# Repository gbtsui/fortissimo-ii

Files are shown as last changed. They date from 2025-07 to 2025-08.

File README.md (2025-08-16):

# fortissimo ii

Hello world!

This is my 2nd attempt at building a keyboard.

I really enjoyed hackpad v2 (even though mine ended up broken...) and I wanted an extra little challenge to build something bigger and get better at soldering. So I designed this ortholinear split keyboard that's ideally meant to be perfect for me; ergonomic design, looks cool, a lot of functionality, and on-the-fly custom language switching (eventually - firmware hasn't caught up to that yet!). Since I'm planning on phasing out my laptop when the school year starts to avoid distractions a bit better, I'm going to hopefully replace it with an iPad so I can take notes more effectively. But because I don't have enough money for an iPad keyboard (I'm not shelling out another $160 after buying a $400 device plus a $100 pencil), and I wanted to challenge myself to design something that might be able to replace it, I designed this instead.

Maybe it's not the prettiest case (blame my awful CAD skills, also it's actually asymmetrical in size) and doesn't have the most beautiful design (I'm no electrical engineer), but hopefully it'll work. 

Also, yes, this keyboard is piano themed. I like pianos. I am not good at playing piano. But I thought it was a cool concept.

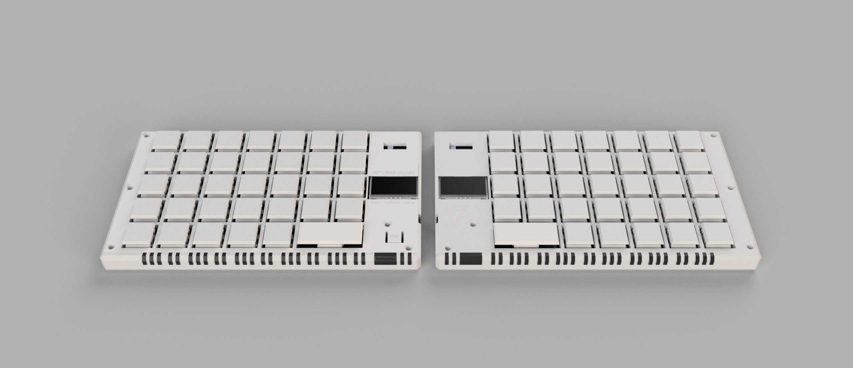
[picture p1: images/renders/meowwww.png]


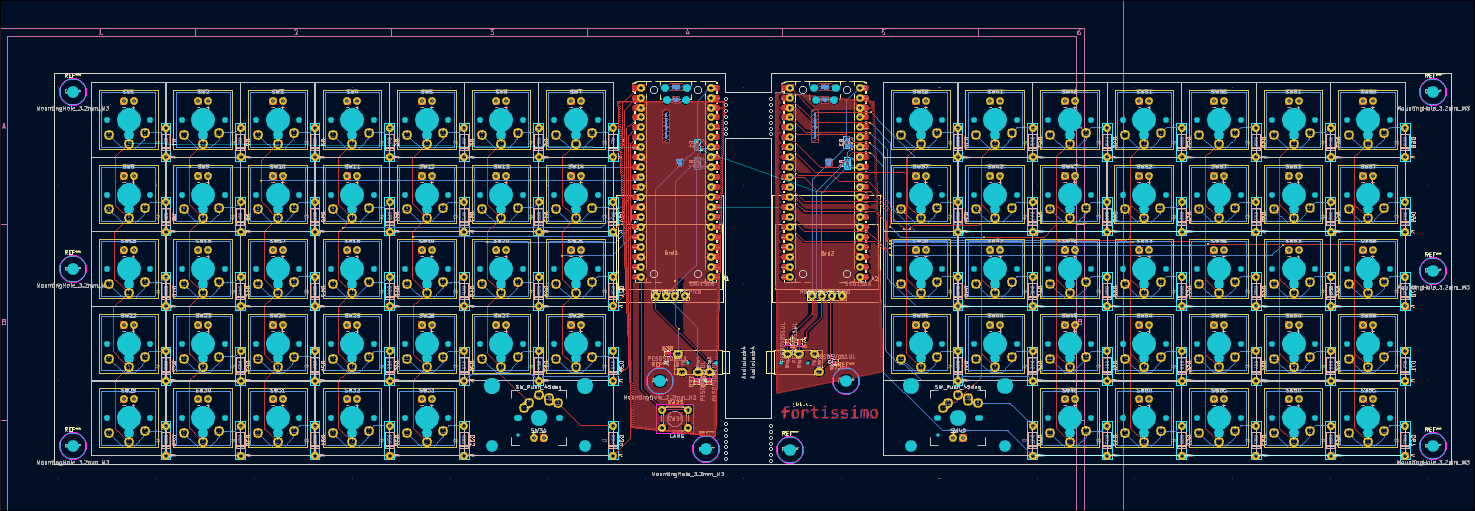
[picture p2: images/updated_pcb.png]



## Bill of Materials

| Item | Cost (each) | Quantity | Subtotal | Shipping |
|---|---|---|---|---|
|[kailh choc v1 brown](https://chosfox.com/collections/kailh-low-profile-switch-pg1350/products/kailh-chocs?variant=42514647646402) | $0.48 (10 pack) | 70 | $33.60 | $8.45 |
|[trrs jack](https://www.aliexpress.com/item/32368285821.html) | $0.069 (20 pack) | 2 | $1.38 | $4.35 |
|[128x64 SSD1306 OLED](https://www.aliexpress.com/item/1005006700828250.html) | $1.15 | 2 | $2.30 | Free Shipping |
| digikey |---|---|---|$8.00|
|[1N4148FS-ND matrix diodes](https://www.digikey.ca/en/products/detail/onsemi/1N4148/458603) | $0.0486 (100 pack) | 70 | $4.86 | - |
|[PESD5V0S1UL ESD protection diode](https://www.digikey.ca/en/products/detail/nexperia-usa-inc/PESD5V0S1BA-QF/18108466) | $0.311 (10 pack) | 6 | $3.11 | - |
|[6mm tactile switch](https://www.digikey.ca/en/products/detail/same-sky-formerly-cui-devices-/TS02-66-50-BK-100-LCR-D/15634294) | $0.15 | 1 | $0.15 | - |
|[raspberry pi pico](https://www.digikey.ca/en/products/detail/raspberry-pi/SC0915/13684020) | $5.75 | 1 | $5.75 | - |
|[4.7k pull up resistor](https://www.digikey.ca/en/products/detail/yageo/RC0603FR-074K7L/727212) | $0.014 (10 pack) | 4 | $0.14 | - |
|[header pin](https://www.digikey.ca/en/products/detail/w-rth-elektronik/61301611121/4846854) | $1.25 | 1 | $1.25 | - | 
|[M3 10mm heatset insert](https://www.digikey.ca/en/products/detail/adafruit-industries-llc/4255/10244656) | $0.1826 (50 pack) | 10 | $9.13 | - |
|[M3 10mm screw](https://www.digikey.ca/en/products/detail/apm-hexseal/RM3X10MM-2701/3712296) | $0.753 (10 pack) | 10 | $7.53 | - |
|PCB| $6.69 (5 pack, including shipping) |  1 | $17.60 | $12.67 + $3.17 | 

Total: $123.44

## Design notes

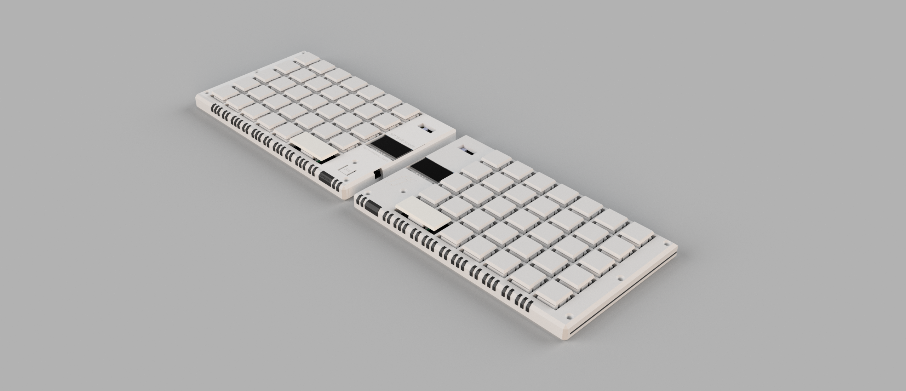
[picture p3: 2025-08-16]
images/renders/awww tism.png

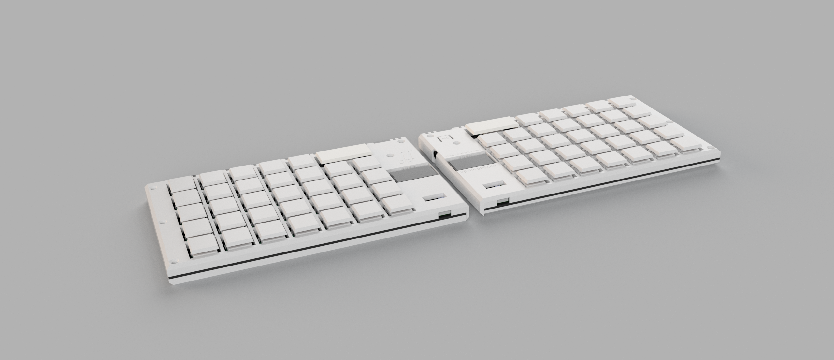
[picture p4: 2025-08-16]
images/renders/my seventheeth lemon, this one is called utah.png

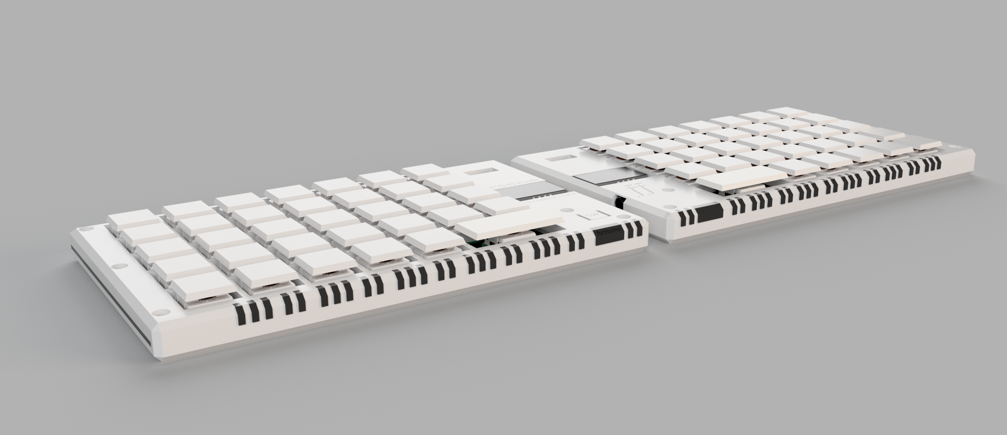
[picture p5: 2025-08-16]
images/renders/fursona 76.png

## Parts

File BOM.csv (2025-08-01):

Id | Designator | Footprint | Quantity | Designation | Supplier and ref
1 | SW9,SW43,SW48,SW21,SW26,SW29,SW52,SW61,SW64,SW56,SW62,SW2,SW54,SW31,SW65,SW25,SW4,SW14,SW8,SW6,SW5,SW67,SW46,SW66,SW18,SW20,SW37,SW1,SW24,SW57,SW27,SW68,SW36,SW32,SW3,SW58,SW33,SW63,SW53,SW22,SW60,SW44,SW11,SW39,SW7,SW23,SW13,SW55,SW10,SW41,SW51,SW12,SW49,SW47,SW17,SW28,SW59,SW19,SW16,SW42,SW50,SW38,SW15,SW30,SW45,SW69 | Low-Profile-Choc-MX | 66 | SW_Push_45deg | Switches | https://chosfox.com/collections/kailh-low-profile-switch-pg1350/products/kailh-chocs?variant=42514647613634
2 | J2,J1 | TRRS-PJ-320A | 2 | AudioJack4 | TRRS | https://keeb.io/products/trrs-jack-3-5mm
3 | D58,D70,D43,D51,D46,D54,D49,D60,D57,D64,D63,D44,D71,D38,D42,D52,D55,D67,D40,D62,D47,D45,D59,D68,D53,D48,D61,D65,D56,D69,D41,D39,D50,D66,D10,D23,D21,D27,D11,D12,D8,D15,D13,D25,D14,D26,D19,D16,D28,D31,D3,D18,D1,D29,D5,D34,D17,D32,D22,D9,D33,D30,D2,D24,D4,D7,D6,D20 | D_DO-35_SOD27_P7.62mm_Horizontal | 68 | D | Matrix Diodes | https://www.digikey.ca/en/products/detail/onsemi/1N4148/458603
4 | D72,D37,D73,D36,D35,D74 | D_SOD-882 | 6 | PESD5V0S1UL | ESD Protection Diode | https://www.digikey.ca/en/products/detail/nexperia-usa-inc/PESD5V0S1BA-QF/18108466
5 | SW34,SW40 | MX-Alps-Choc-2U-StabFlip | 2 | SW_Push_45deg | Switches | https://chosfox.com/collections/kailh-low-profile-switch-pg1350/products/kailh-chocs?variant=42514647613634
6 | Brd2,Brd1 | 128x64OLED | 2 | SSD1306 | OLED Display | https://www.aliexpress.com/item/1005006700828250.html
7 | SW35 | SW_PUSH_6mm | 1 | LANG | Language Switch Button | https://www.digikey.ca/en/products/detail/same-sky-formerly-cui-devices-/TS02-66-50-BK-100-LCR-D/15634294
8 | A1,A2 | RaspberryPi_Pico_Common_Unspecified | 2 | RaspberryPi_Pico | MCU | https://www.digikey.ca/en/products/detail/raspberry-pi/SC0915/13684020
9 | R4,R1,R3,R2 | R_0603_1608Metric | 4 | 4.7k | I2C Pull-Up Resistors | https://www.digikey.ca/en/products/detail/yageo/RC0603FR-074K7L/727212
10 | "" |  | 1 | ;Header Pins" | https://www.digikey.ca/en/products/detail/w-rth-elektronik/61301611121/4846854
11 | "" |  | 10 |  | Heatset Inserts for Screws | https://www.digikey.ca/en/products/detail/adafruit-industries-llc/4255/10244656
12 | "" |  | 10 |  | Screws | https://www.canadarobotix.com/products/831?variant=14423565533233&country=CA&currency=CAD&gQT=1

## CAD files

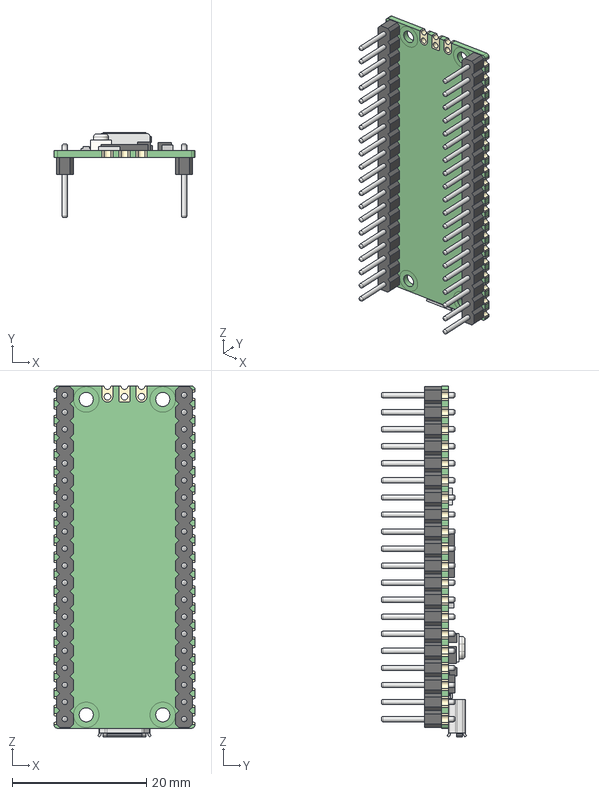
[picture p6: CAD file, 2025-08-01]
3d_models/sources/PICO_PinsDown.STEP
21.0 x 12.7 x 52.3 mm
PICO_REF_BOARD.STEP
PICO_REF_USB.STEP
PICO_REF_SWITCH.STEP
PICO_REF_MICROCONTROLLER.STEP
PICO_REF_LED.STEP
PICO_REF_ONSEMI.STEP
PICO_BOURNS.STEP
PICO_MURATA.STEP x 2
PICO_RICHTEK.STEP
PICO_DIODES.STEP
PICO_AEL.STEP
PICO_PIN_HEADERS
PICO_HEADER_HOLES

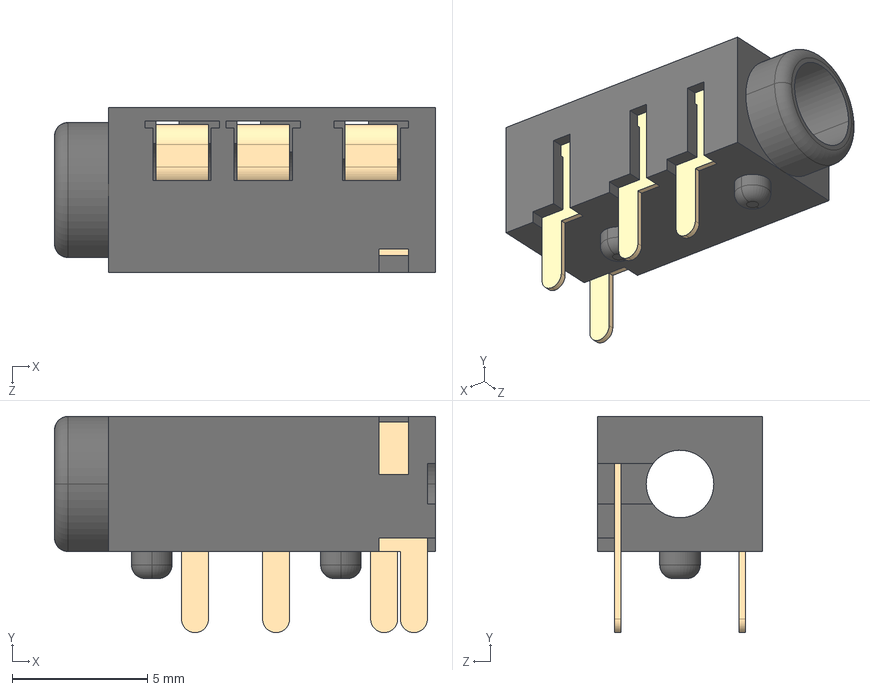
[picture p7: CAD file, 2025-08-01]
3d_models/sources/PJ320A/PJ320A.STEP
14.1 x 8.00 x 6.10 mm
PJ320A蝶褲
PJ320A-Pin-A x 3
PJ320A-Pin-B

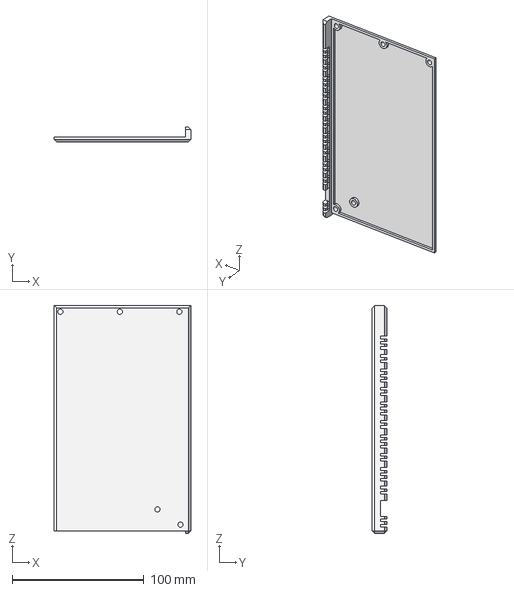
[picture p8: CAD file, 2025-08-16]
prod/Case Left Side Bottom.step
104.0 x 11.5 x 173.3 mm

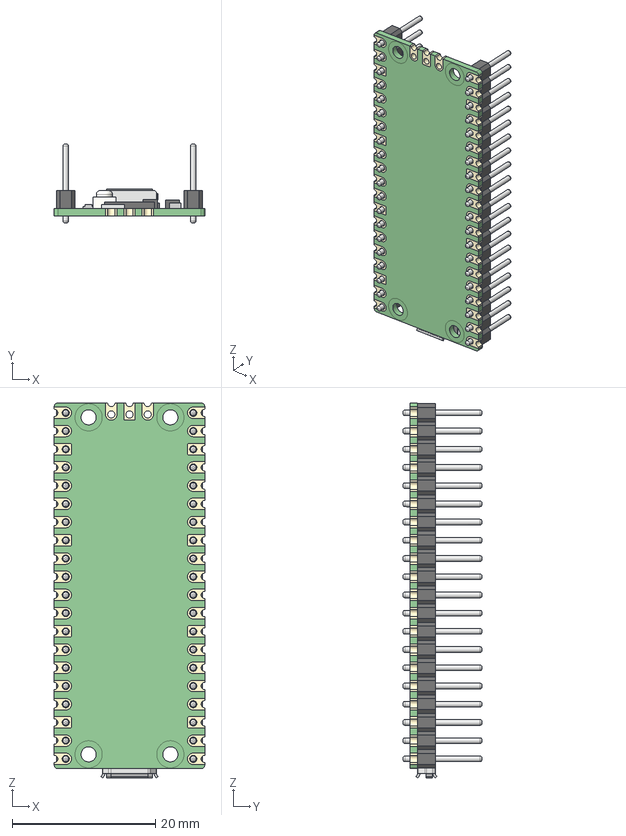
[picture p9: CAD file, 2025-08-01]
3d_models/sources/PICO_PinsUp.STEP
21.0 x 11.0 x 52.3 mm
PICO_REF_BOARD.STEP
PICO_REF_USB.STEP
PICO_REF_SWITCH.STEP
PICO_REF_MICROCONTROLLER.STEP
PICO_REF_LED.STEP
PICO_REF_ONSEMI.STEP
PICO_BOURNS.STEP
PICO_MURATA.STEP x 2
PICO_RICHTEK.STEP
PICO_DIODES.STEP
PICO_AEL.STEP
PICO_PIN_HEADERS
PICO_HEADER_HOLES

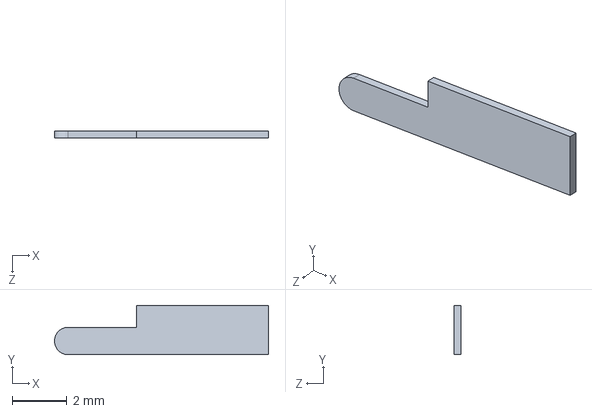
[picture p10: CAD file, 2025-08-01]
3d_models/sources/PJ320A/PJ320A-Pin-B.sldprt
7.80 x 1.80 x 0.25 mm

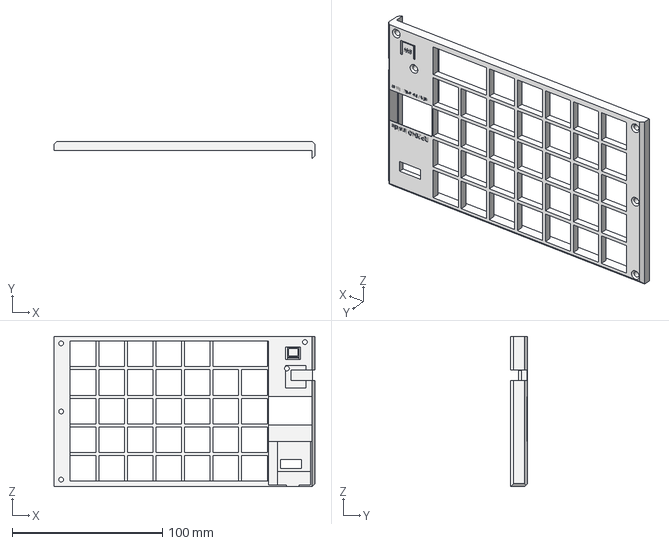
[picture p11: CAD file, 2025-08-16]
prod/Case Left Side Top.step
173.4 x 11.5 x 100.0 mm

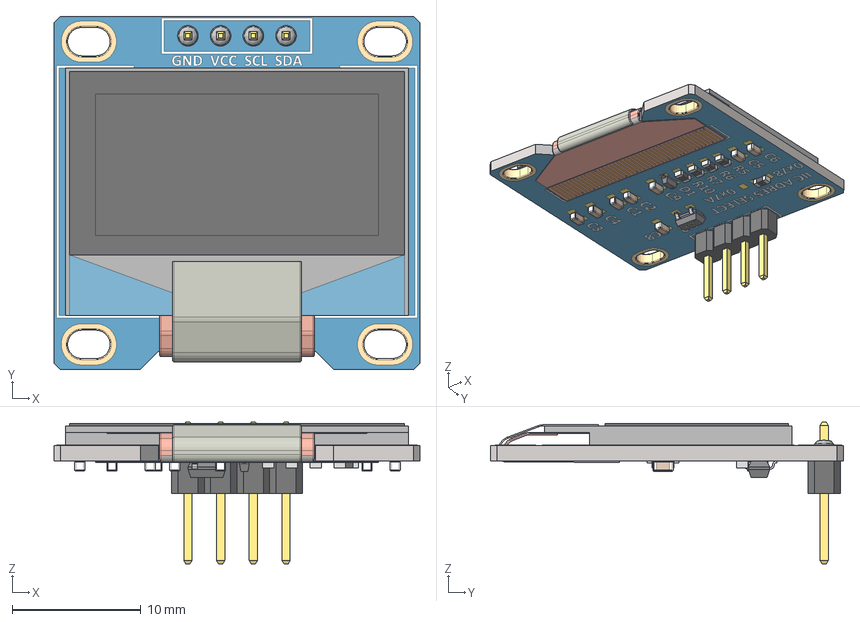
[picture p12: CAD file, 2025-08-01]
3d_models/sources/Pantalla OLED 0.96'' 128x64.stp
28.4 x 27.4 x 11.0 mm
SOT-23_TOR
RES_CR16_MTK_1 x 4
RES_CR16_MTK
SOD323F_DIO

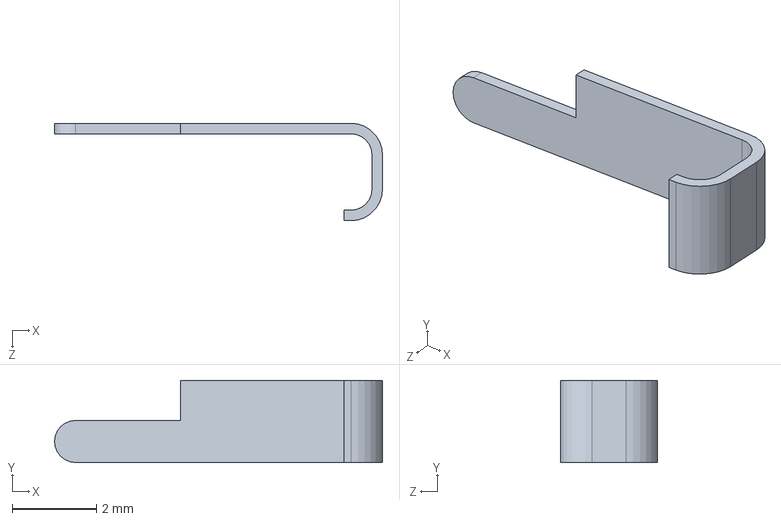
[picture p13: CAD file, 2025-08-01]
3d_models/sources/PJ320A/PJ320A-Pin-A.sldprt
7.80 x 1.95 x 2.32 mm

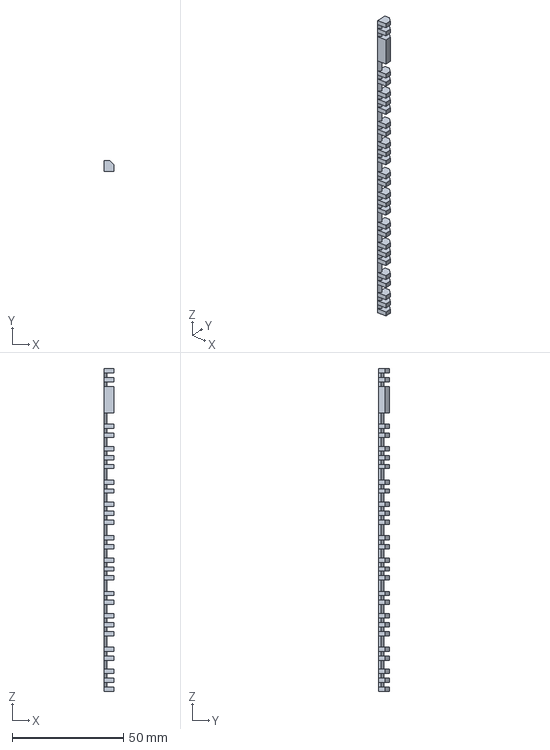
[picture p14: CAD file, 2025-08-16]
prod/right side keys.step
4.50 x 5.00 x 145.0 mm

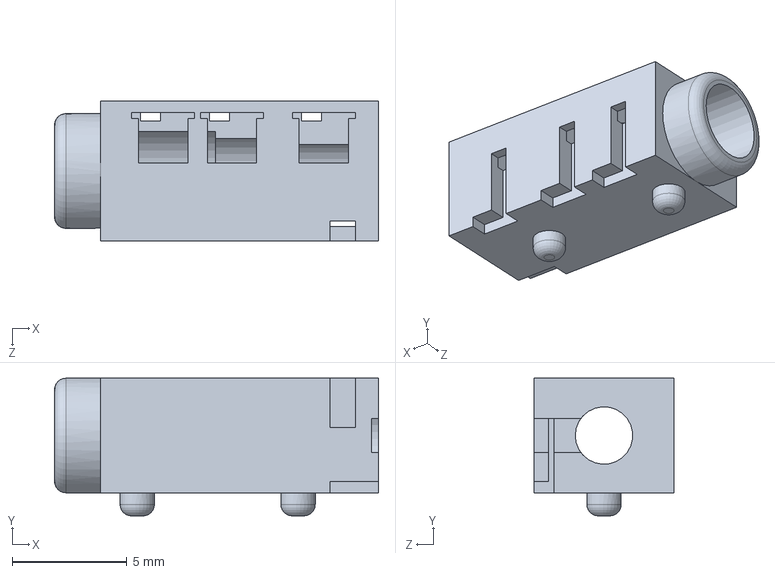
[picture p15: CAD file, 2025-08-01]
3d_models/sources/PJ320A/PJ320A胶壳.SLDPRT
14.1 x 6.00 x 6.10 mm

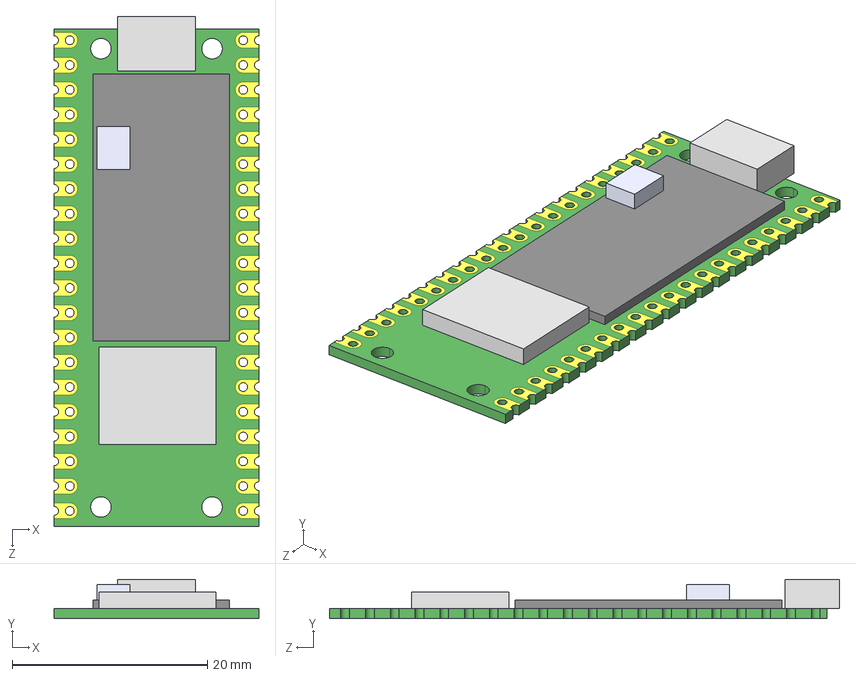
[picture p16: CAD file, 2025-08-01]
3d_models/sources/RasPicoW.STEP
21.0 x 4.01 x 52.3 mm

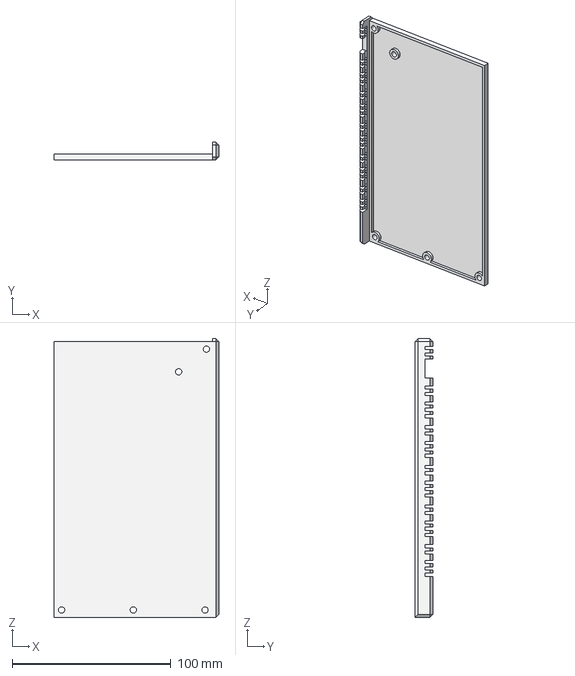
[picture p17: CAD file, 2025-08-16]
prod/Case Right Side Bottom.step
104.0 x 11.5 x 176.0 mm

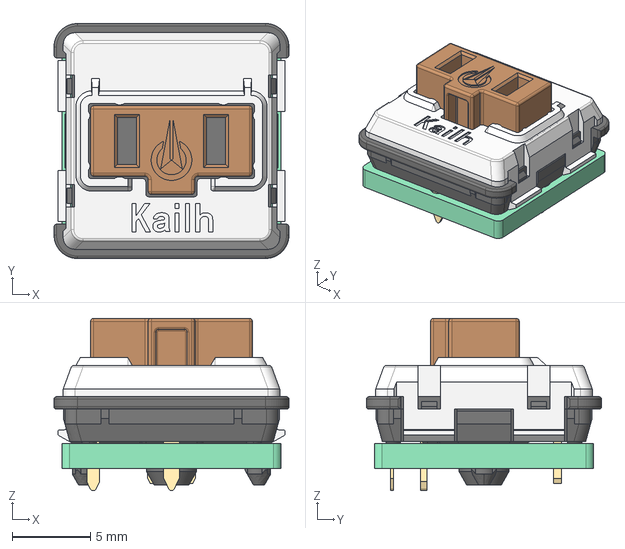
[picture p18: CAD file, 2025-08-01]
3d_models/sources/Kailh Choc Low Profile Switch.step
15.0 x 15.0 x 11.0 mm

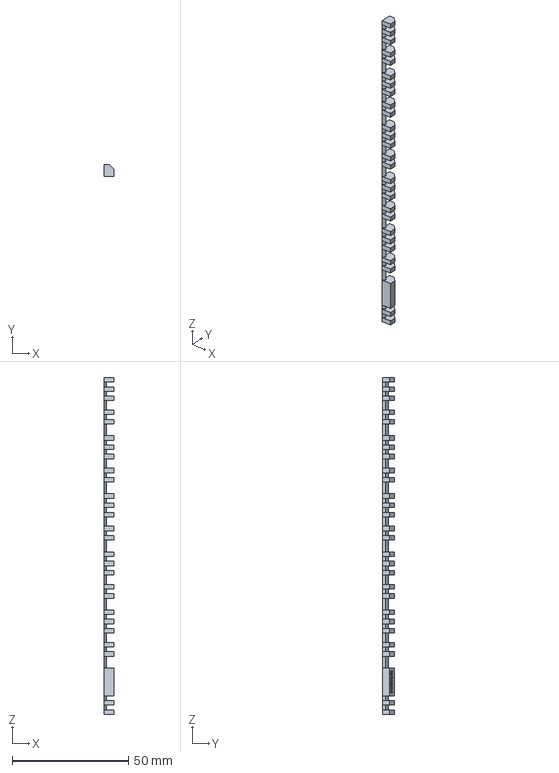
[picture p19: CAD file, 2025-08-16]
prod/left side keys.step
4.50 x 5.00 x 145.0 mm

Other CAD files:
3d_models/sources/RasPico.STEP
prod/Case Right Side Top.step
3d_models/sources/PJ320A/PJ320A.SLDASM
3d_models/sources/RasPico.SLDPRT
3d_models/sources/RasPico.STL
3d_models/sources/RasPicoW.SLDPRT
3d_models/sources/RasPicoW.STL

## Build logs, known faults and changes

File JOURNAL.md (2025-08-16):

---
title: "Fortissimo-II"
author: "gbtsui"
description: "A split ortholinear coding/multilanguage keyboard for efficient typing and language switching!"
created_at: "2025-06-04"
---

Est. time spent: 19h

## 4 June 2025
So this is the start of my keyboard! Hi! I'm Gabriel. This is going to be probably my first medium-scale PCB project!
I'm going to actually start design work for this on Sunday because I'm going to compete with my friends to see who can
keyboard the fastest. But my basic design concept is:

- split ortholinear design
- physical switch to toggle between languages/scripts (US QWERTY, French Canadian Multilingual, Greek layout, custom Hiragana layout, custom Katakana layout)
- low profile design
- neopixels reacting to events and languages
- OLED displays per side
- USB hub
- RP2040 (either a stamp or just a breakout board)

Yeah, that's about it!

## 13 June 2025

Estimated time spent: 4h

So I actually forgot to journal the work I did. On Sunday (8 June), I got most of the schematic done and started working on the PCB itself.

Unfortunately, I was really really dissatisfied with the PCB because it was sad and bad and low quality. So today I deleted the work I had so far and started fresh.

A problem that I noticed was that my hub had to be able to handle 5V1A through VBUS. I could use thicker copper traces (2oz?) but that would be kinda expensive. Then again, I'm using the same amount of copper regardless so that it can all handle the current. So I honestly have no idea what to do now; I'm just going to wire it up anyways and hope for the best. Also, the components that I'm using need to be able to handle all of that.

I have 35 SK6812Minis, a PGA2040, an SSD1306, and 3 downstream USB ports. I might be fried, honestly. I need to be running, like, what, 2.1A? to get everything running? I might lower the neopixel brightness so my board doesn't implode on itself.

Gonna start wiring now. Wish me luck.

## 13 June 2025

Wired up the USB hub part without ground yet.



## 17 June 2025

Estimated time spent: 3h

Finished up pretty much the entire left side! DRC keeps throwing errors but they're problems with the footprints I used, not with my actual design (hopefully).



So I forgot that neopixels existed and spent the entirety of this morning trying to route them all. It was not fun. As well, I forgot how to do a ground pour and spent half an hour routing that before I realized I could just ground pour it. But it's mostly done now! Just time to do the other half. I know the layout, time to repeat it!

## 29 July 2025

Time spent: 4h

I kinda forgot I was working on this because of Neighborhood. But anyways, with like 2 days left to design, I realized that my original design was far too ambitious. So I started again from the schematic, replacing the PGA2040 (they stopped manufacturing thoughs) with a regular Raspberry Pi Pico, dropped the LEDs, rotary encoder and USB hub. 
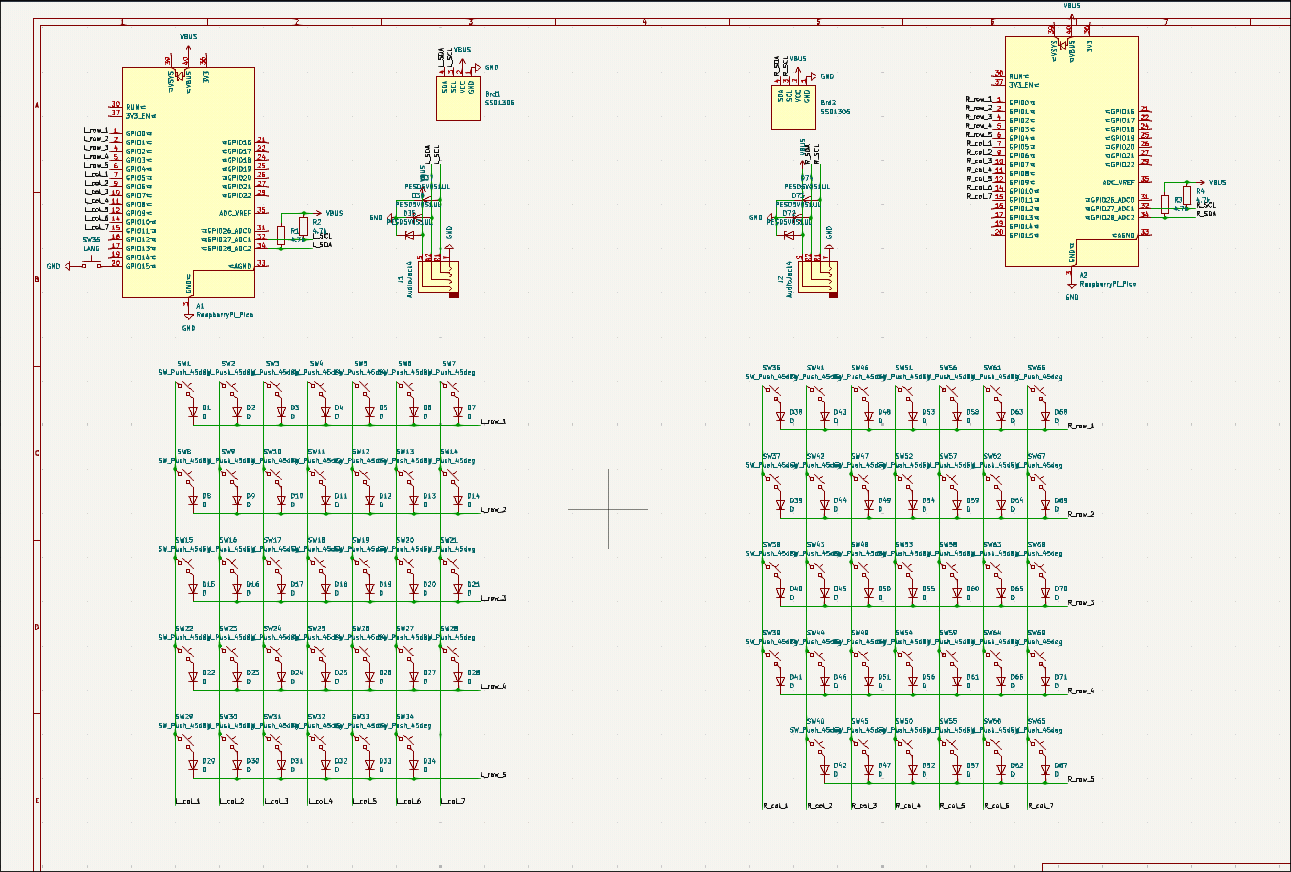
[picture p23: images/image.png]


This is what it ended up looking like. So I took it and routed the PCB again, ending up with this. 

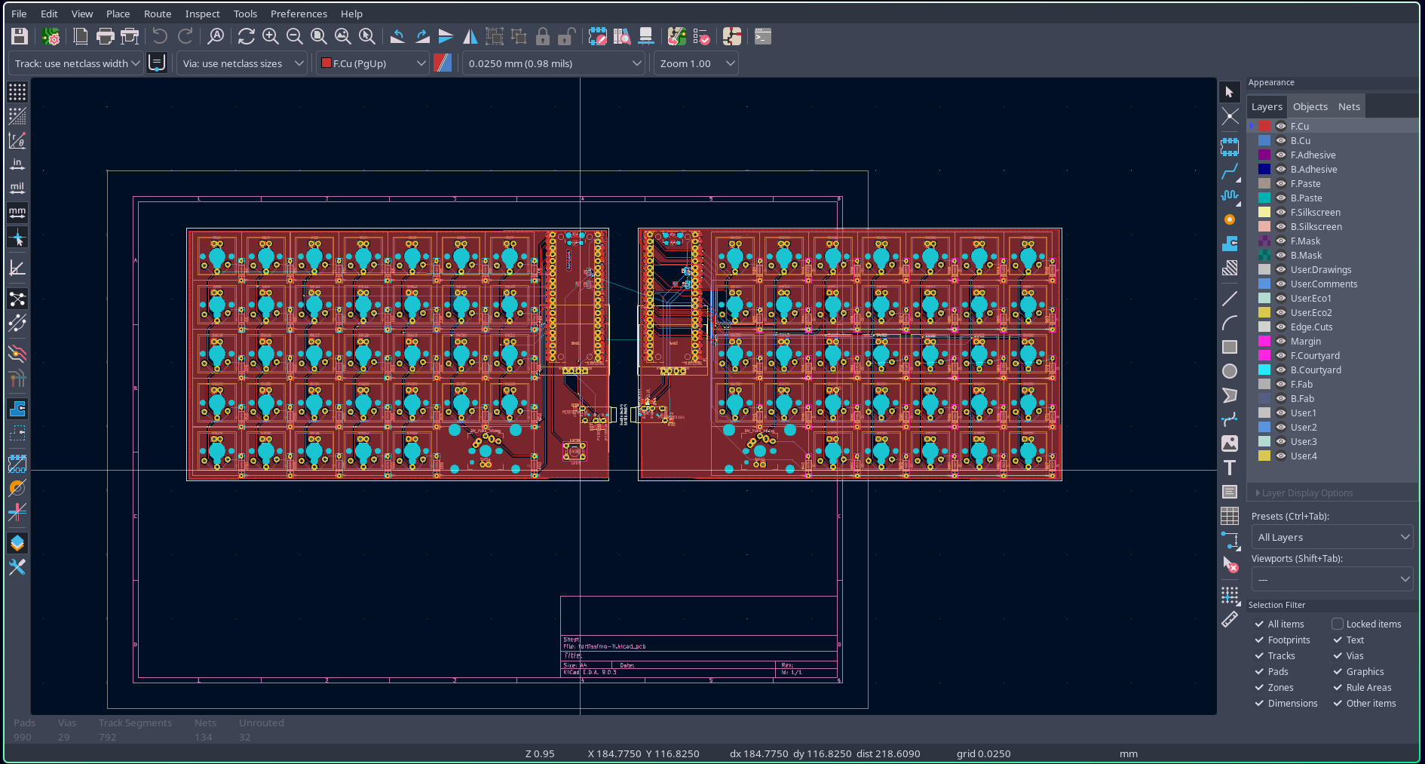
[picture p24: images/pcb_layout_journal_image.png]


I also added the TRRS jack so that both halves could communicate with I2C. I'm pretty sure QMK supports that by default but I'm not sure, so tomorrow I"m going to have to actually code the firmware for it. Hopefully it doesn't take too long.

I'm overall pretty happy with how this is looking. It's a lot cleaner. I'm not sure how mounting it to a case will work but we'll get to that when we get there. 

## 30 July 2025

Time spent: 1.5h

So I tried making some firmware. I honestly have no idea what I'm doing so I just stole from the docs a lot. Not even sure what any of this does, but it should line up with my layout.

It should communicate using I2C but to be fully honest I have no idea how to implement that. 

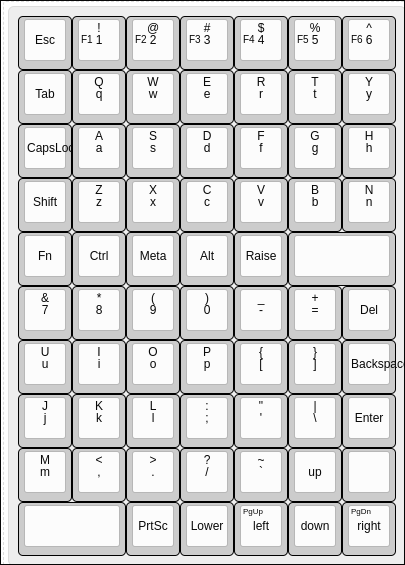
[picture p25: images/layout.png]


According to QMK, split keyboards should look like this. It looks really cursed but it should work out.

I'm honestly not too too sure what the ideal layout for Raise and Lower should look like. Maybe something like Fn (which I don't think really works yet) but I think it's one of the things that I'll figure out when I actually manufacture.

## 31 July 2025

Time spent: 6.5h

Okay, so, last day, so things are getting really stressful. Got up at 4am.

I made the BOM, which is pretty cool. Turns out I'll probably need header pins too. 

Also, I redid the board outline and added mounting holes for easier design later.



 Ended up moving all of the footprints to a local library so I could add 3D models, and I think it looks pretty good so far. 

 Started work on the case. It was actually surprisingly difficult (mostly because I'm bad at CAD but whatever). I ended up using 3.2mm holes for the top part and 4mm holes for the bottom (since I'll be adding heatset inserts).

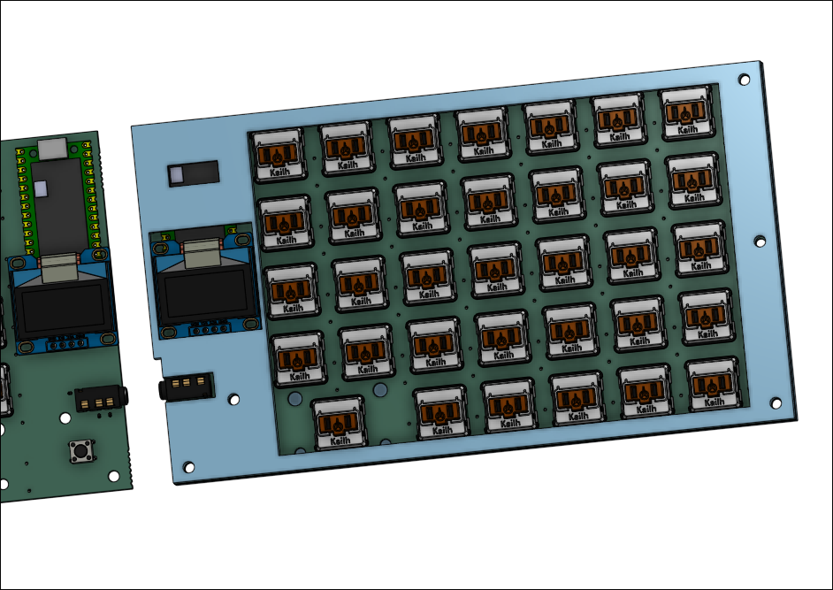
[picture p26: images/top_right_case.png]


The hole on the pico is intentionally large so you can hit the BOOTSEL button on both the left and right halves which is cool.

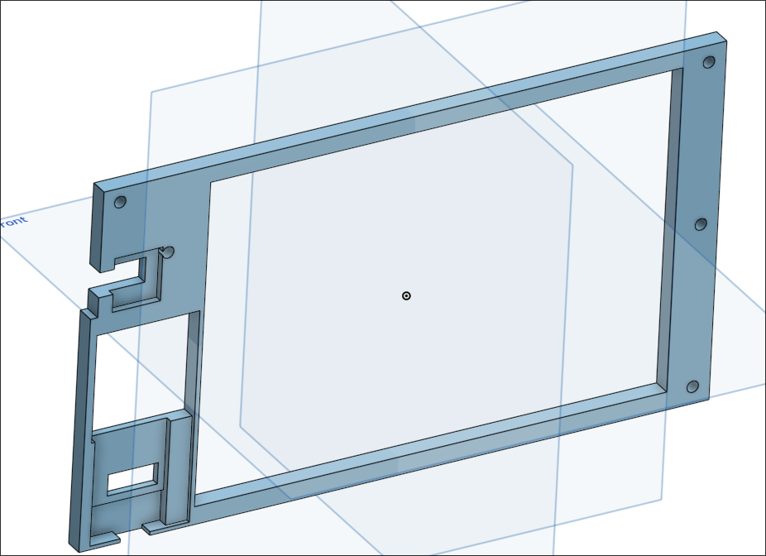
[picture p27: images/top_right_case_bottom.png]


The top right case is looking pretty good, just gonna mirror it for the left side with a few tweaks since for some reason the holes on the left aren't in the exact same positions.

It's 5pm as I'm typing this and I lowkey got up at 4am to finish all of this.

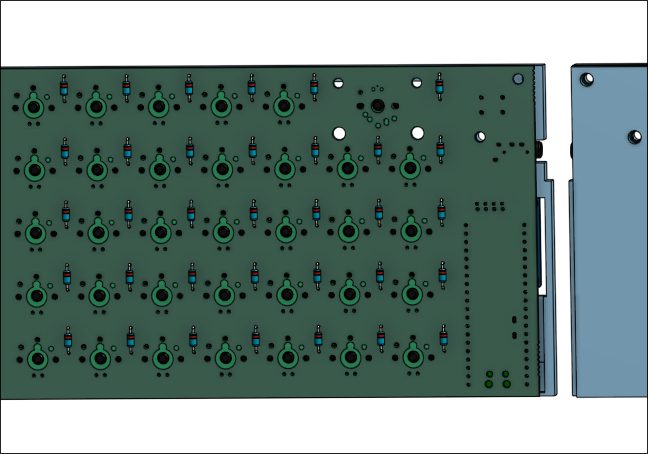
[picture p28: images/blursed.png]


I just realized my two halves are different sizes.

Took me a while but finally fixed the asymmetry. (Not in the PCB, though, I'm too lazy for that.)

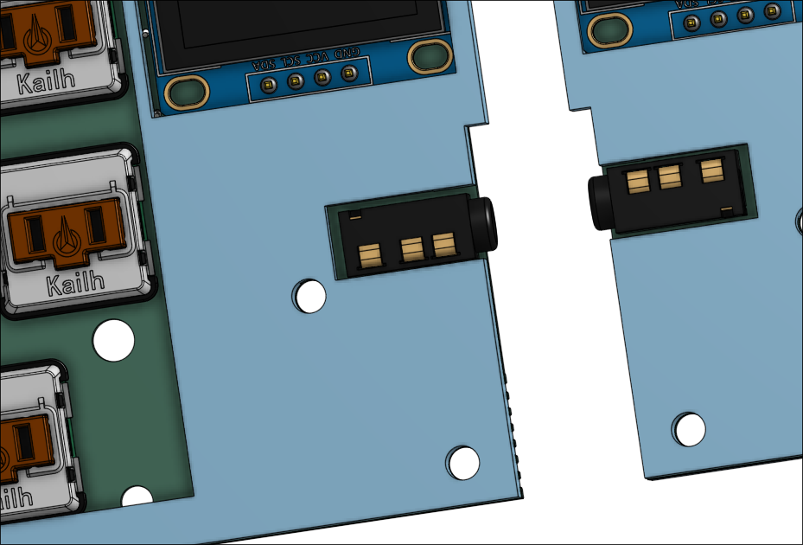
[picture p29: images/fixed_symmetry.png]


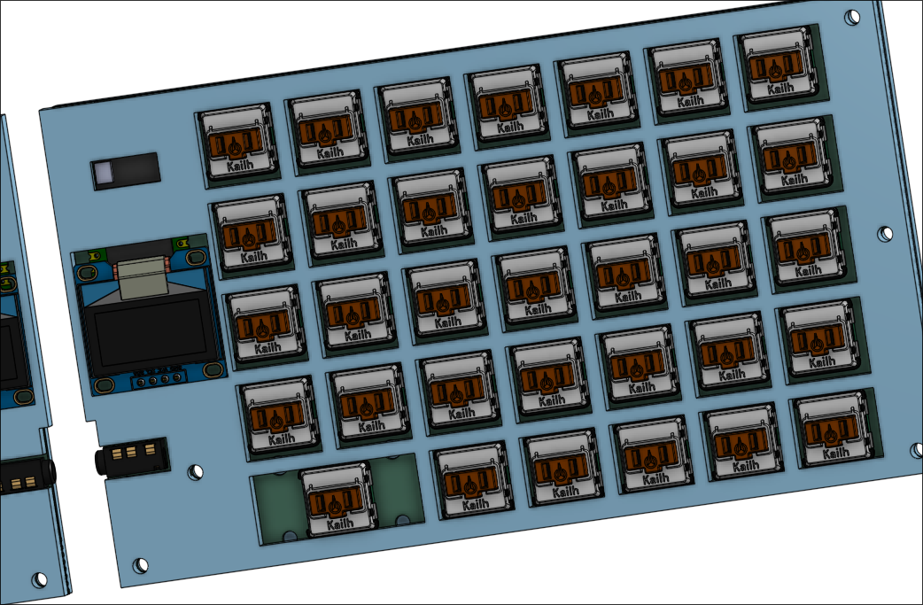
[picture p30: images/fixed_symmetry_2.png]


Also made this grill thing (not sure what it's called) but it should protect the diode contacts underneath from getting really dirty.

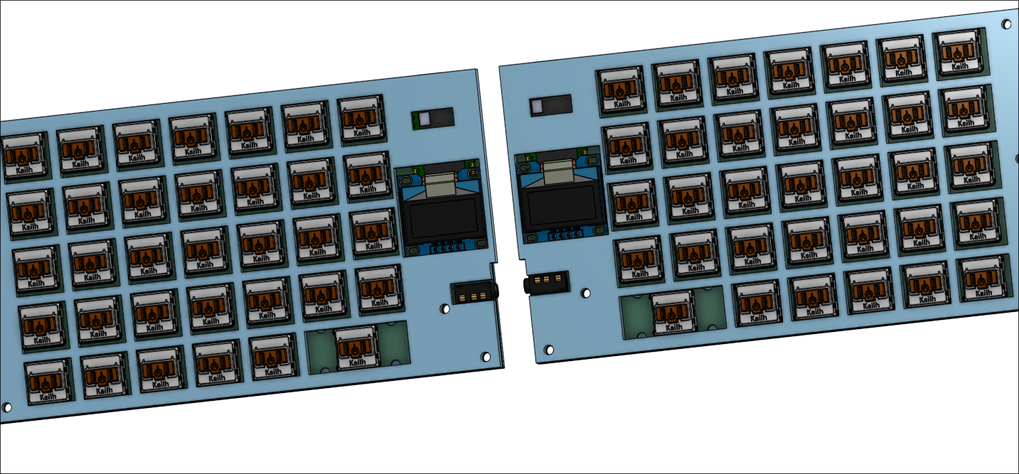
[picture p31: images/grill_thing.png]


Man, it's 6:45. I need to get this done but also eat dinner.

Almost forgot the lang switch button!
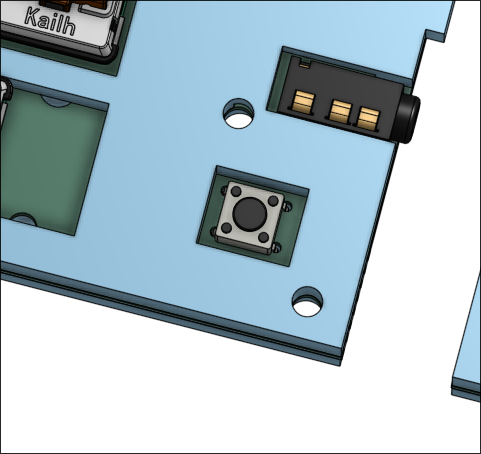
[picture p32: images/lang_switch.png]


But yeah, full assembly is looking amazing, I think. Not too bad for what is effectively my first attempt at CAD. I think this literally took me about 5 hours to make. Honestly not sure what kind of keycaps I'm going to use but I think I'll custom design some!

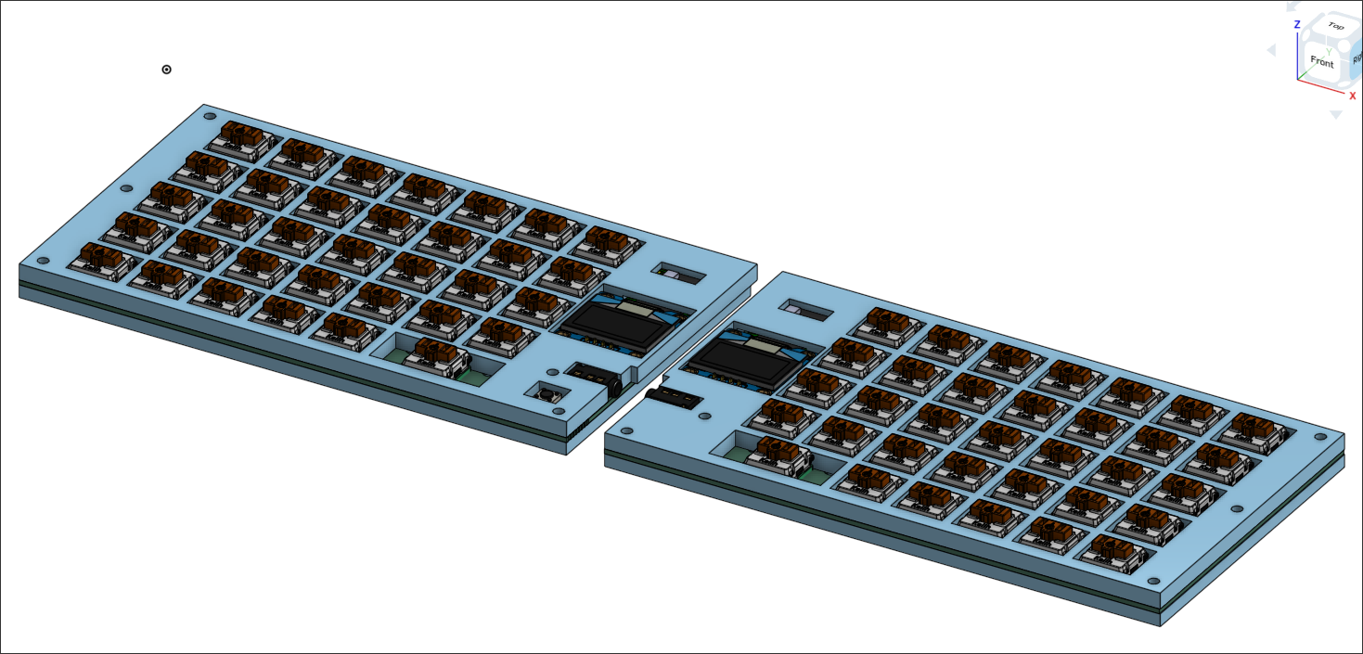
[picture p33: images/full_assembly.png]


Okay, firmware time.

So, it's kinda weird, because I'm pretty unfamiliar with how QMK and split keyboard comms work. I'm assuming that through using I2C QMK deals with it automatically since I'm not doing custom data sending (as of yet). But, I set it up according to the docs, and I can only wait to flash it to my pico to see if it'll work or not. If it works as intended, great! I have a barebones functioning keyboard from which I can build all of my cool advanced functionality that I unfortunately do not know how to do yet without testing. If it doesn't, that's okay too! It means I get to figure out what's wrong.

## 05 August 2025
So I remade the case a bit, fixing the spacing between the keys and adding a lot of chamfers. I think it looks a lot better with the added text and stuff but to be completely honest I still don't know how to make it look super aesthetic. 

## 12 August 2025
I got rejected again for the second time which is sad. So I spent as much time as I could making everything look cool and polished. I will be sad if I get rejected again.

Anyways, since my keyboard is piano keyboard (pun intended) themed, I added some black keys similar to those found on an actual piano on the bottom edge. The keys are still white on the render but I'm not sure if I'll pattern them with black and white when I build.

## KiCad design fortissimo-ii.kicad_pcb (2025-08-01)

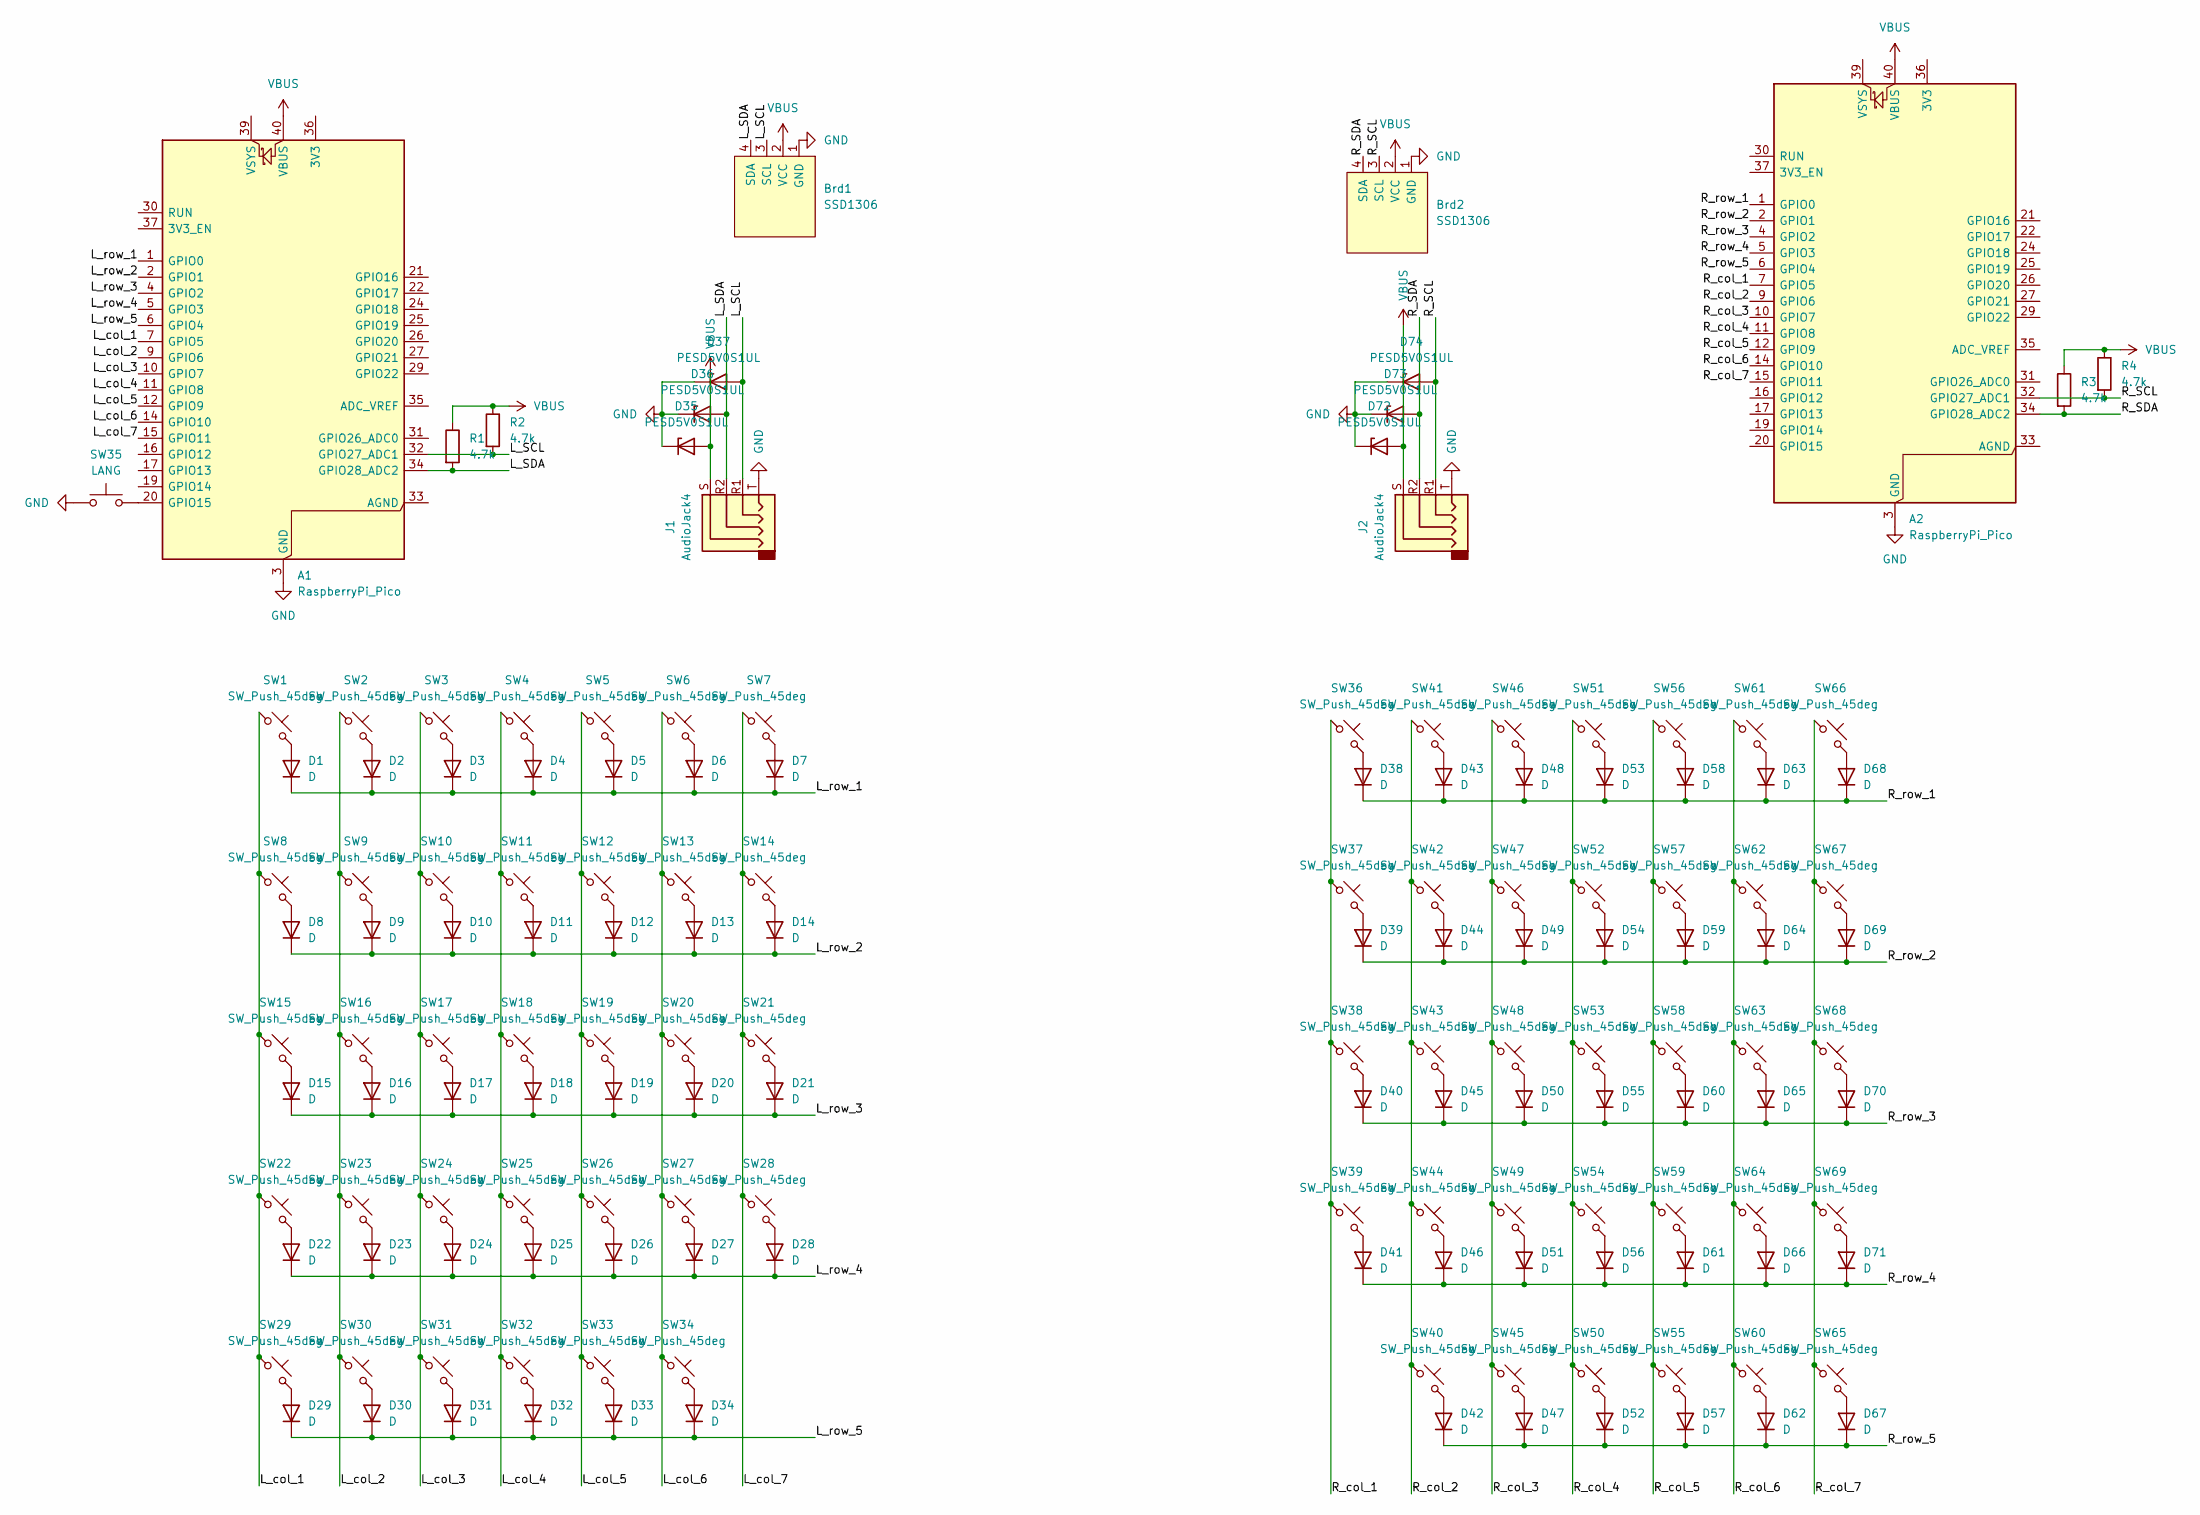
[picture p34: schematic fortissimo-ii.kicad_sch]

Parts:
A1, A2: RaspberryPi_Pico; RaspberryPi_Pico_Common_Unspecified
Brd1, Brd2: SSD1306; 128x64OLED
D1, D2, D3, D4, D5, D6, D7, D8, D9, D10, D11, D12, D13, D14, D15, D16, D17, D18, D19, D20, D21, D22, D23, D24, D25, D26, D27, D28, D29, D30, D31, D32, D33, D34, D38, D39, D40, D41, D42, D43, D44, D45, D46, D47, D48, D49, D50, D51, D52, D53, D54, D55, D56, D57, D58, D59, D60, D61, D62, D63, D64, D65, D66, D67, D68, D69, D70, D71: D; D_DO-35_SOD27_P7.62mm_Horizontal
D35, D36, D37, D72, D73, D74: PESD5V0S1UL; D_SOD-882
J1, J2: AudioJack4; TRRS-PJ-320A
R1, R2, R3, R4: 4.7k; R_0603_1608Metric
SW1, SW2, SW3, SW4, SW5, SW6, SW7, SW8, SW9, SW10, SW11, SW12, SW13, SW14, SW15, SW16, SW17, SW18, SW19, SW20, SW21, SW22, SW23, SW24, SW25, SW26, SW27, SW28, SW29, SW30, SW31, SW32, SW33, SW36, SW37, SW38, SW39, SW41, SW42, SW43, SW44, SW45, SW46, SW47, SW48, SW49, SW50, SW51, SW52, SW53, SW54, SW55, SW56, SW57, SW58, SW59, SW60, SW61, SW62, SW63, SW64, SW65, SW66, SW67, SW68, SW69: SW_Push_45deg; Low-Profile-Choc-MX
SW34, SW40: SW_Push_45deg; MX-Alps-Choc-2U-StabFlip
SW35: LANG; SW_PUSH_6mm

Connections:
/L_SCL: A1.32 (GPIO27_ADC1), Brd1.3 (SCL), D37.2 (A), J1.R1, R2.2
/L_SDA: A1.34 (GPIO28_ADC2), Brd1.4 (SDA), D36.2 (A), J1.R2, R1.2
/L_col_1: A1.7 (GPIO5), SW1.1, SW8.1, SW15.1, SW22.1, SW29.1
/L_col_2: A1.9 (GPIO6), SW2.1, SW9.1, SW16.1, SW23.1, SW30.1
/L_col_3: A1.10 (GPIO7), SW3.1, SW10.1, SW17.1, SW24.1, SW31.1
/L_col_4: A1.11 (GPIO8), SW4.1, SW11.1, SW18.1, SW25.1, SW32.1
/L_col_5: A1.12 (GPIO9), SW5.1, SW12.1, SW19.1, SW26.1, SW33.1
/L_col_6: A1.14 (GPIO10), SW6.1, SW13.1, SW20.1, SW27.1, SW34.1
/L_col_7: A1.15 (GPIO11), SW7.1, SW14.1, SW21.1, SW28.1
/L_row_1: A1.1 (GPIO0), D1.1 (K), D2.1 (K), D3.1 (K), D4.1 (K), D5.1 (K), D6.1 (K), D7.1 (K)
/L_row_2: A1.2 (GPIO1), D8.1 (K), D9.1 (K), D10.1 (K), D11.1 (K), D12.1 (K), D13.1 (K), D14.1 (K)
/L_row_3: A1.4 (GPIO2), D15.1 (K), D16.1 (K), D17.1 (K), D18.1 (K), D19.1 (K), D20.1 (K), D21.1 (K)
/L_row_4: A1.5 (GPIO3), D22.1 (K), D23.1 (K), D24.1 (K), D25.1 (K), D26.1 (K), D27.1 (K), D28.1 (K)
/L_row_5: A1.6 (GPIO4), D29.1 (K), D30.1 (K), D31.1 (K), D32.1 (K), D33.1 (K), D34.1 (K)
/R_SCL: A2.32 (GPIO27_ADC1), Brd2.3 (SCL), D74.2 (A), J2.R1, R4.2
/R_SDA: A2.34 (GPIO28_ADC2), Brd2.4 (SDA), D73.2 (A), J2.R2, R3.2
/R_col_1: A2.7 (GPIO5), SW36.1, SW37.1, SW38.1, SW39.1
/R_col_2: A2.9 (GPIO6), SW40.1, SW41.1, SW42.1, SW43.1, SW44.1
/R_col_3: A2.10 (GPIO7), SW45.1, SW46.1, SW47.1, SW48.1, SW49.1
/R_col_4: A2.11 (GPIO8), SW50.1, SW51.1, SW52.1, SW53.1, SW54.1
/R_col_5: A2.12 (GPIO9), SW55.1, SW56.1, SW57.1, SW58.1, SW59.1
/R_col_6: A2.14 (GPIO10), SW60.1, SW61.1, SW62.1, SW63.1, SW64.1
/R_col_7: A2.15 (GPIO11), SW65.1, SW66.1, SW67.1, SW68.1, SW69.1
/R_row_1: A2.1 (GPIO0), D38.1 (K), D43.1 (K), D48.1 (K), D53.1 (K), D58.1 (K), D63.1 (K), D68.1 (K)
/R_row_2: A2.2 (GPIO1), D39.1 (K), D44.1 (K), D49.1 (K), D54.1 (K), D59.1 (K), D64.1 (K), D69.1 (K)
/R_row_3: A2.4 (GPIO2), D40.1 (K), D45.1 (K), D50.1 (K), D55.1 (K), D60.1 (K), D65.1 (K), D70.1 (K)
/R_row_4: A2.5 (GPIO3), D41.1 (K), D46.1 (K), D51.1 (K), D56.1 (K), D61.1 (K), D66.1 (K), D71.1 (K)
/R_row_5: A2.6 (GPIO4), D42.1 (K), D47.1 (K), D52.1 (K), D57.1 (K), D62.1 (K), D67.1 (K)
GND: A1.3 (GND), A1.8 (GND), A1.13 (GND), A1.18 (GND), A1.23 (GND), A1.28 (GND), A1.38 (GND), A2.3 (GND), A2.8 (GND), A2.13 (GND), A2.18 (GND), A2.23 (GND), A2.28 (GND), A2.38 (GND), Brd1.1 (GND), Brd2.1 (GND), D35.1 (K), D36.1 (K), D37.1 (K), D72.1 (K), D73.1 (K), D74.1 (K), J1.T, J2.T, SW35.2
unnamed: A1.20 (GPIO15), SW35.1
unnamed: D1.2 (A), SW1.2
unnamed: D2.2 (A), SW2.2
unnamed: D3.2 (A), SW3.2
unnamed: D4.2 (A), SW4.2
unnamed: D5.2 (A), SW5.2
unnamed: D6.2 (A), SW6.2
unnamed: D7.2 (A), SW7.2
unnamed: D8.2 (A), SW8.2
unnamed: D9.2 (A), SW9.2
unnamed: D10.2 (A), SW10.2
unnamed: D11.2 (A), SW11.2
unnamed: D12.2 (A), SW12.2
unnamed: D13.2 (A), SW13.2
unnamed: D14.2 (A), SW14.2
unnamed: D15.2 (A), SW15.2
unnamed: D16.2 (A), SW16.2
unnamed: D17.2 (A), SW17.2
unnamed: D18.2 (A), SW18.2
unnamed: D19.2 (A), SW19.2
unnamed: D20.2 (A), SW20.2
unnamed: D21.2 (A), SW21.2
unnamed: D22.2 (A), SW22.2
unnamed: D23.2 (A), SW23.2
unnamed: D24.2 (A), SW24.2
unnamed: D25.2 (A), SW25.2
unnamed: D26.2 (A), SW26.2
unnamed: D27.2 (A), SW27.2
unnamed: D28.2 (A), SW28.2
unnamed: D29.2 (A), SW29.2
unnamed: D30.2 (A), SW30.2
unnamed: D31.2 (A), SW31.2
unnamed: D32.2 (A), SW32.2
unnamed: D33.2 (A), SW33.2
unnamed: D34.2 (A), SW34.2
unnamed: D38.2 (A), SW36.2
unnamed: D39.2 (A), SW37.2
unnamed: D40.2 (A), SW38.2
unnamed: D41.2 (A), SW39.2
unnamed: D42.2 (A), SW40.2
unnamed: D43.2 (A), SW41.2
unnamed: D44.2 (A), SW42.2
unnamed: D45.2 (A), SW43.2
unnamed: D46.2 (A), SW44.2
unnamed: D47.2 (A), SW45.2
unnamed: D48.2 (A), SW46.2
unnamed: D49.2 (A), SW47.2
unnamed: D50.2 (A), SW48.2
unnamed: D51.2 (A), SW49.2
unnamed: D52.2 (A), SW50.2
unnamed: D53.2 (A), SW51.2
unnamed: D54.2 (A), SW52.2
unnamed: D55.2 (A), SW53.2
unnamed: D56.2 (A), SW54.2
unnamed: D57.2 (A), SW55.2
unnamed: D58.2 (A), SW56.2
unnamed: D59.2 (A), SW57.2
unnamed: D60.2 (A), SW58.2
unnamed: D61.2 (A), SW59.2
unnamed: D62.2 (A), SW60.2
unnamed: D63.2 (A), SW61.2
unnamed: D64.2 (A), SW62.2
unnamed: D65.2 (A), SW63.2
unnamed: D66.2 (A), SW64.2
unnamed: D67.2 (A), SW65.2
unnamed: D68.2 (A), SW66.2
unnamed: D69.2 (A), SW67.2
unnamed: D70.2 (A), SW68.2
unnamed: D71.2 (A), SW69.2
VBUS: A1.40 (VBUS), A2.40 (VBUS), Brd1.2 (VCC), Brd2.2 (VCC), D35.2 (A), D72.2 (A), J1.S, J2.S, R1.1, R2.1, R3.1, R4.1

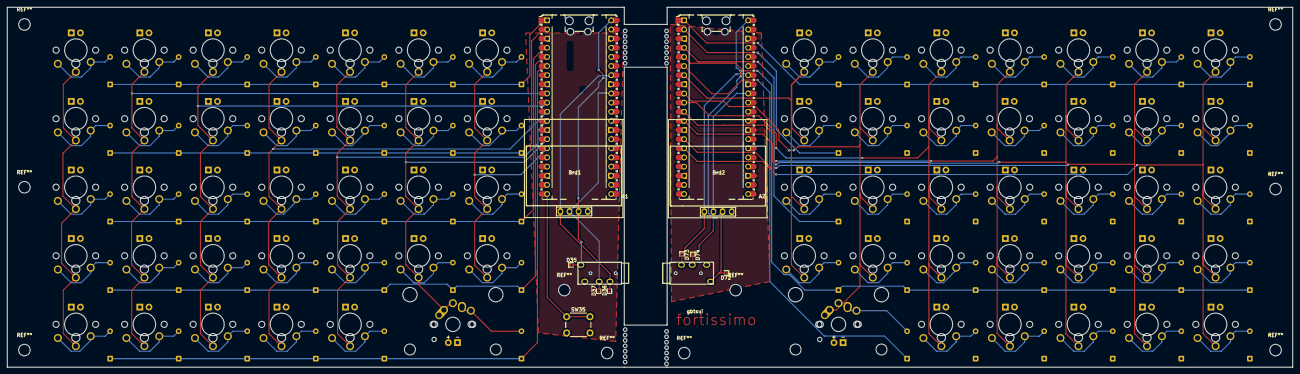
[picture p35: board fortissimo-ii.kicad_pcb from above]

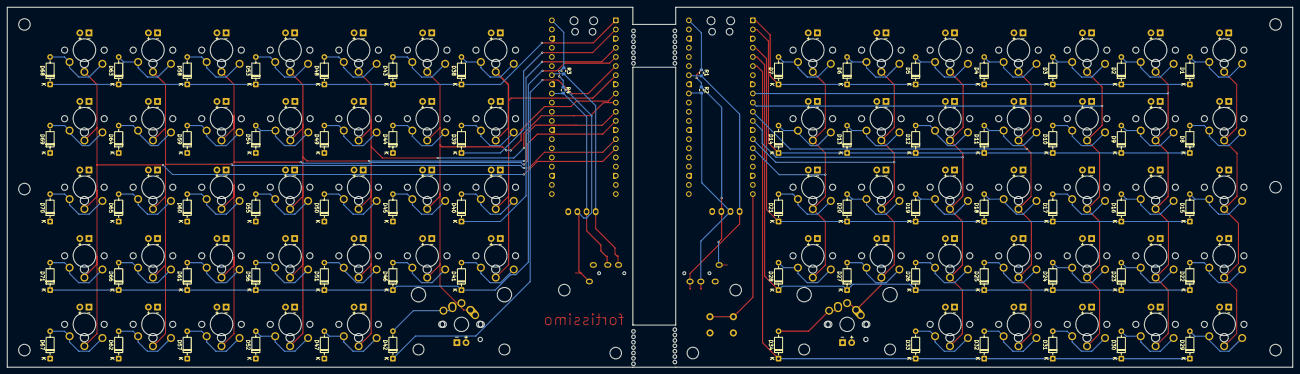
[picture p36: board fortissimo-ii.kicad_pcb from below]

Board: 2 copper layers, 357.2 x 100.0 mm, 153 parts (72 on the bottom side), 99 nets.

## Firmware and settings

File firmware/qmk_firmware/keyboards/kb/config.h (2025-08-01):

#ifndef CONFIG_H
#define CONFIG_H

#include "config_common.h"

/* USB Device descriptor parameter */
#define VENDOR_ID       0xFEED
#define PRODUCT_ID      0x6060
#define DEVICE_VER      0x0001
#define MANUFACTURER    qmkbuilder
#define PRODUCT         keyboard
#define DESCRIPTION     Keyboard

/* key matrix size */
#define MATRIX_ROWS 10
#define MATRIX_COLS 7

/* key matrix pins */
#define MATRIX_ROW_PINS_RIGHT { GP0, GP1, GP2, GP3, GP4 }
#define MATRIX_COL_PINS_RIGHT { GP5, GP6, GP7, GP8, GP9, GP10, GP11 }
#define MATRIX_ROW_PINS_LEFT { GP0, GP1, GP2, GP3, GP4 }
#define MATRIX_COL_PINS_LEFT { GP5, GP6, GP7, GP8, GP9, GP10, GP11 }
#define UNUSED_PINS

#define EE_HANDS
#define MASTER_LEFT
#define USE_I2C


/* COL2ROW or ROW2COL */
#define DIODE_DIRECTION COL2ROW

/* number of backlight levels */

#ifdef BACKLIGHT_PIN
#define BACKLIGHT_LEVELS 3
#endif

/* Set 0 if debouncing isn't needed */
#define DEBOUNCING_DELAY 5

/* Mechanical locking support. Use KC_LCAP, KC_LNUM or KC_LSCR instead in keymap */
#define LOCKING_SUPPORT_ENABLE

/* Locking resynchronize hack */
#define LOCKING_RESYNC_ENABLE

/* key combination for command */
#define IS_COMMAND() ( \
    keyboard_report->mods == (MOD_BIT(KC_LSHIFT) | MOD_BIT(KC_RSHIFT)) \
)

/* prevent stuck modifiers */
#define PREVENT_STUCK_MODIFIERS


#ifdef RGB_DI_PIN
#define RGBLIGHT_ANIMATIONS
#define RGBLED_NUM 0
#define RGBLIGHT_HUE_STEP 8
#define RGBLIGHT_SAT_STEP 8
#define RGBLIGHT_VAL_STEP 8
#endif

#endif

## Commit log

2025-06-13 created schematic v1
    [fortissimo-ii.kicad_sch]
2025-06-17 wired up neopixels
    [fortissimo-ii.kicad_pcb]
2025-06-17 finished left side!
    [fortissimo-ii.kicad_pcb, fortissimo-ii.kicad_sch]
2025-07-30 changes from jul 29
    [fortissimo-ii.kicad_pcb, fortissimo-ii.kicad_sch]
2025-08-01 basically the entire thing
    [BOM.csv, Case Left Side Bottom.step, Case Left Side Top.step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]
2025-08-05 fix BOM
2025-08-16 final polish
    [Case Left Side Bottom.step, Case Left Side Top.step, Case Right Side Bottom.step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]
